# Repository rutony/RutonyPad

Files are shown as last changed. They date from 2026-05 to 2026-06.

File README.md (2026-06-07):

# RutonyPad

Небольшая беспроводная BLE-клавиатура на 8 кнопок для управления OBS и другими горячими клавишами. Проект вырос из идеи “сделать за пару часов подарок”, а в итоге прошел через китайский клон nRF52840, тестер пинов, несколько версий корпуса, пайку, веб-конфигуратор и отдельный режим настройки.

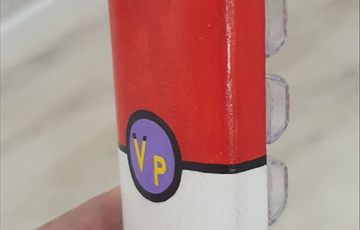
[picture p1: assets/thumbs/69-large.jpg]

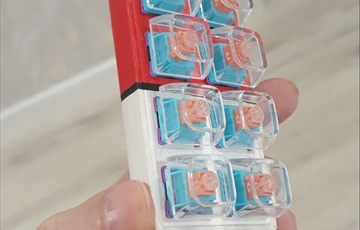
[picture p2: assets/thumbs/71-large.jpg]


## Что внутри

- прошивка устройства: [firmware/RutonyPad10/RutonyPad10.ino](firmware/RutonyPad10/RutonyPad10.ino);
- тестер пинов для китайского nRF52840 Pro Micro: [firmware/TesterPins/TesterPins.ino](firmware/TesterPins/TesterPins.ino);
- веб-страница для настройки клавиш: [web/index.html](web/index.html);
- STL-модель корпуса: [assets/models/RutonyPad-Box-v3.2.stl](assets/models/RutonyPad-Box-v3.2.stl);
- STL-крышки/клавиш: [assets/models/RutonyPad-Buttons-v1.1.stl](assets/models/RutonyPad-Buttons-v1.1.stl);
- фотографии процесса и схемы: [assets/images](assets/images).

Полезные внешние ссылки:

- схема устройства в Cirkit Designer: <https://app.cirkitdesigner.com/project/74aa2c99-3412-43d3-a665-44ffdaccba8f>;
- корпус в Tinkercad: <https://www.tinkercad.com/things/2l7U8HlfgIG-rutonypad-v31>.

## Как пользоваться

1. Залить прошивку [RutonyPad10.ino](firmware/RutonyPad10/RutonyPad10.ino) на nRF52840.
2. Подключить кнопки к пинам: `D33`, `D2`, `D20`, `D21`, `D23`, `D1`, `D12`, `D11`.
3. Подключить делитель батареи к `D18`.
4. В обычном режиме использовать устройство как Bluetooth-клавиатуру и определяется как RutonyPad.
5. Для настройки, удалить устройство если оно спарено, зажать крайние кнопки по диагонали примерно на 10 секунд. Устройство должно уже определиться как RutonyCfg. Значит оно перешло в режим конфигурации. Не добавлять его как обычное блютус устройство.
6. Открыть [web/index.html](web/index.html) в браузере с поддержкой Web Bluetooth. И подключить RutonyCfg.
7. Настроить клавиши и вернуться в режим клавиатуры.
8. Если не была нажата кнопка режима клавиатуры, зажать диагональные кнопки для смены режима - в режим клавиатуры.

## Что получилось

Получилось маленькое беспроводное устройство на 8 клавиш, которое:

- работает как BLE HID-клавиатура;
- умеет показывать заряд батареи;
- живет от аккумулятора примерно 2,5-3 недели;
- переключается в отдельный режим конфигурации комбинацией крайних кнопок по диагонали;
- настраивается через веб-страницу без перепрошивки;
- собрано в напечатанном корпусе.

## Идея

Все началось на стриме у Хели: <https://twitch.tv/vpaname>. Она любит танцевать, но управлять компьютером, когда стоишь, не очень удобно. Нужна была мини-клавиатура для OBS и горячих клавиш.

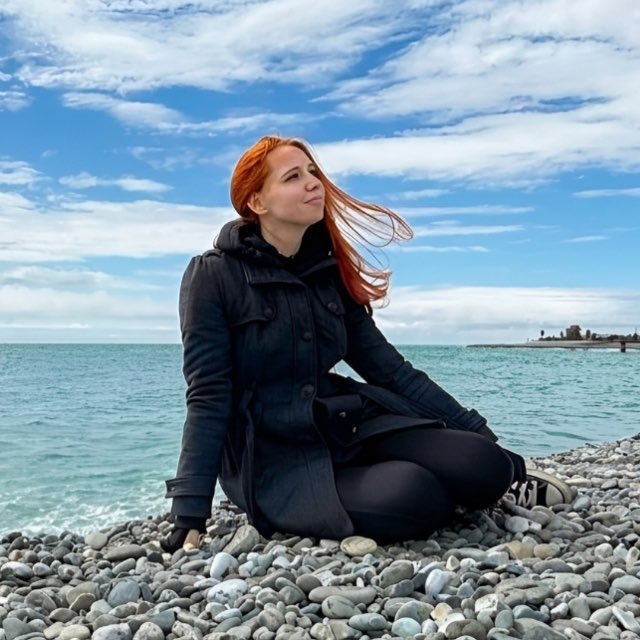
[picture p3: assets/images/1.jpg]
Хели


Быстрый поиск показал, что готовые устройства существуют, но стоят ощутимо дороже, чем хотелось. Я прикинул бюджет в районе 2-3 тысяч рублей и решил сделать свою версию. До дня рождения оставалось около трех месяцев, так что идея выглядела как хороший подарок и проект “буквально на пару часов”. По итогу, конечно, эти “пара часов” превратились в 3 месяца безудержного веселья. Но было интересно попробовать себя в роли инженера, коим я и являюсь. Опыт есть в создании устройств, но они в основном были в разы проще и не такие комплексные. 

## Контроллер и первые грабли

После общения с нейронкой стало казаться, что задача простая: нужна небольшая плата, Bluetooth, несколько кнопок и аккумулятор. Wi-Fi не нужен, основа устройства - контроллер.

Я заказал на Ozon модуль NRF52840, совместимый с Nice!Nano V2.0 / Bluetooth Pro Micro NRF52840. С AliExpress ждать пришлось бы дольше, да и было непонятно, что именно приедет.

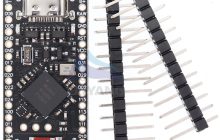
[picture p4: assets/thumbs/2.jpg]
Контроллер


Пока плата ехала, я прикинул корпус:

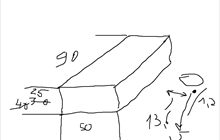
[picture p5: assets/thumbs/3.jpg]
Первый набросок корпуса


Когда контроллер приехал, начались первые тесты в Arduino IDE. Задачи были две: написать прошивку и потом все это спаять. На макетной плате все вело себя отвратительно: то работает, то отваливается, то кажется, что ошибка в коде, то кажется, что в проводах.

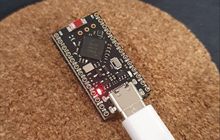
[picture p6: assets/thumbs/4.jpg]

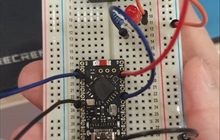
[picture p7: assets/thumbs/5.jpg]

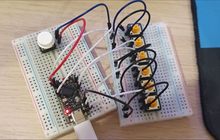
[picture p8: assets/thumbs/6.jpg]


В итоге выяснилось, что часть проблем была в макетной плате. Эти платы удобны для быстрых проверок, но если контакт плохой, начинается настоящая лотерея. А еще обнаружилась проблема с самим китайским клоном контроллера.

В комплекте была схема пинов, но нигде не было сказано, что часть пинов не работает или имеет другую нумерацию. Несколько дней ушло на ковыряние неочевидных проблем.

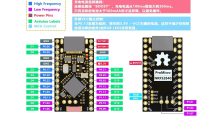
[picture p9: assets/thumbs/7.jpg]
Схема пинов


Чтобы разобраться, я написал отдельный скетч-тестер. Он сканирует пины: я замыкаю их на GND и смотрю, какой пин реально отзывается. Так стало понятно, что на китайском клоне половина заявленных пинов действительно может оказаться бесполезной.

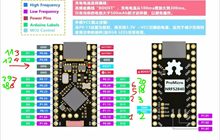
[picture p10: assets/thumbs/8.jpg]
Тест пинов


Скетч тестера лежит здесь: [firmware/TesterPins/TesterPins.ino](firmware/TesterPins/TesterPins.ino).

## Прошивка

Прошивку сначала помогала собирать нейронка, но она честно наворотила ровно то, что я попросил: 8 кнопок, Bluetooth и отдельную кнопку включения. Проблема была в том, что часть выбранных пинов не работала, а отдельная кнопка питания в итоге оказалась не такой уж нужной.

Пока я правил прошивку, появилась идея использовать служебную комбинацию кнопок для перехода в режим настройки. Логика получилась такая:

- в обычном режиме устройство работает как BLE HID-клавиатура;
- если зажать две крайние кнопки примерно на 5 секунд, устройство перезагружается в режим конфигурации;
- в режиме конфигурации оно не создает HID-клавиатуру, зато его можно настроить через веб-страницу;
- повторная служебная комбинация или кнопка на странице возвращает устройство в обычный режим.

Еще одна важная доработка - отображение заряда аккумулятора в Bluetooth-устройствах. Для этого пришлось отказаться от отдельной кнопки питания, поставить резисторы и снимать показания с контроллера заряда. Зато теперь в системе видно процент батареи.

По умолчанию устройство большую часть времени спит. Сон почти не ест аккумулятор. По расчетам и в реальности автономность получилась примерно 2,5-3 недели.

Основная прошивка лежит здесь: [firmware/RutonyPad10/RutonyPad10.ino](firmware/RutonyPad10/RutonyPad10.ino).

## Компоненты

Основные детали, которые использовались:

- модуль NRF52840, совместимый с Nice!Nano V2.0 / Bluetooth Pro Micro NRF52840;
- аккумулятор 602035, 500 mAh, 3,7 V;
- контроллер заряда TP4056 USB Type-C с защитой;
- кабели JST PH 2.0 мм;
- свитчи Redragon Bullet-R;
- сокеты Kailh MX Socket, чтобы не паять свитчи намертво;
- паяльник ALIENTEK T90B;
- припой ПОС-61 с канифолью.

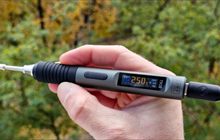
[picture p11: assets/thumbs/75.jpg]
ALIENTEK T90B


Так как я паял не так что бы много и паять пришлось бы достаточно много мелких деталей, я бы одурел делать это советским паяльником. Поэтому был при обретен новый современный. Паяльник, кстати, оказался очень крутым, покупался по наводке Гайвера (Заметки Ардуинщика, иногда посматривал его видосы, а тут еще и пригодилось): быстрый разогрев за 5-10 секунд, питание от обычного повербанка, настройка температуры и удобная ручка. Важный момент: нужен мягкий USB-C кабель под высокий вольтаж. В комплекте он был.

## Схема

Финальная схема подключения компонентов:

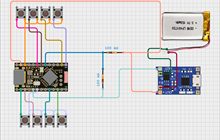
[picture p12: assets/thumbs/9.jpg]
Схема распайки


Проект схемы: <https://app.cirkitdesigner.com/project/74aa2c99-3412-43d3-a665-44ffdaccba8f>

Изначально в схеме была отдельная кнопка включения и программирования, но позже я от нее отказался.

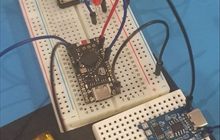
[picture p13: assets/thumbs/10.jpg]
Планирование схемы


## Пайка и первые тесты

Когда прошивка, схема и веб-страница для программирования клавиш были готовы, началась пайка.

Сначала припаивается силовой провод. Тут важно сделать все аккуратно: ничего не должно торчать, все закрывается оплеткой.

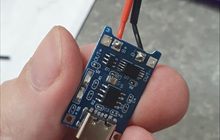
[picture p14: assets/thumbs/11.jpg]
Пайка питания


Потом первые тесты: устройство уже видно в компьютере без прямого подключения. На заднем плане еще старая схема с отдельной кнопкой включения. Но уже видно что устройство определилось как блютус клавиатура.

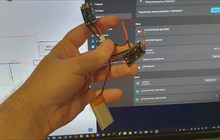
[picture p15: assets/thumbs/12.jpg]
Первый беспроводной тест


Дальше - пайка всего устройства. Почти сразу стало понятно, что без “третьей руки” будет тяжело: контакты мелкие, плату нужно держать, а видеть хочется больше. Ее я заказывал с перерывом в неделю, я в этот момент был в Москве на Гамеднях и с подругой Олей (<https://www.twitch.tv/trolechka_>) стояли в ночной шавухе. Я ей рассказывал чуть деталей, мол вот собираю уже почти все готово, но паять трудно, была бы третья рука, было бы проще. А сам думаю какого черта.. И там же заказал, пока готовилась шавуха. Хеля, кстати, отказалась от шавухи и не пошла с нами, она на диете.

Лупа с третьей рукой нереально сильно упростила жизнь и ускорила пайку.

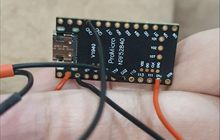
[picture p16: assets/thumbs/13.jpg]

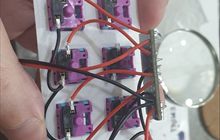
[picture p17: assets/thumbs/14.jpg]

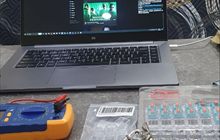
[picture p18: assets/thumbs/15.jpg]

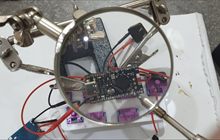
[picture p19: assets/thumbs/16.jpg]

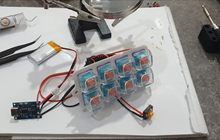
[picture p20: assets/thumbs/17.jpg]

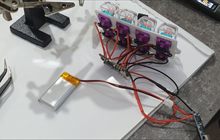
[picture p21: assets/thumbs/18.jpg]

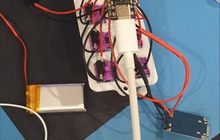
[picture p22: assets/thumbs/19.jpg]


## Веб-конфигуратор

Для настройки клавиш сделана отдельная страница: [web/index.html](web/index.html).

Она подключается к устройству в режиме конфигурации через Web Bluetooth и позволяет назначать поведение кнопок. После настройки можно вернуть устройство в режим клавиатуры прямо со страницы.

Пришлось повозиться со страницей, в целом нейронка все быстро сверстала, даже какой то общий стиль. Но она упорно путала идентификаторы устройства. Поэтому нужна была постоянная правка, то в скетче, то на самой странице. Но я справился.

Саму же страницу я разместил у себя на сайте. Вспомнив такой фильм как Сеть (1995), я добавил маленький символ Пи, по нажатию на который открывается конфигуратор. В фильме Сандра Буллок, через него получала доступ к базе данных через бекдок. Тут конечно не взлом как в фильме, но все же :D

## Корпус

Отдельная глава боли - корпус и покраска.

Сначала я сделал корпус высотой 40 мм, но после печати стало понятно, что он смотрится плохо: слишком высокий, плюс при печати лежа появились “лесенки”. Тогда я решил печатать стоя (не я сам стоял, а модель, я в этот момент занимался своими делами) и уменьшил высоту до 25 мм.

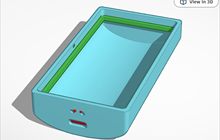
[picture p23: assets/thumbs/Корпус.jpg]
Проект корпуса


Модель в Tinkercad: <https://www.tinkercad.com/things/2l7U8HlfgIG-rutonypad-v31>

У модели версия 3.1, потому что было сделано 3 разные версии, под 40мм, под 25мм, и потом я понял что защелки которые я хотел сделать это ерунда, достаточно просто сделать "балкончик". То нужна полка для контроллера заряда, то больше места под крышку, то защелки получаются слишком хлипкими. Всего модель печаталась 11 раз, до конца печати дожили 4 версии. В одном из заходов даже сломался принтер: датчик температуры сопла показывал постоянные 220 градусов...

Сначала я решил перепрошить принтер, вдруг это программная какая то ошибка. Результата никакого не было. Пришлось разобрать сопло принтера, проверить ничего ли не сломалось, проверить нужно ли менять датчик. Было предположение что из-за постоянных срывов печати сопло ударило по модели, от чего она слетела и повредился датчик. Но он пришел в себя и заработал после разбоки. Поэтому принтер благополучно был собран обратно и отправлен печатать новую деталь.

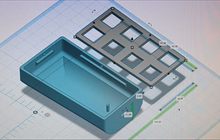
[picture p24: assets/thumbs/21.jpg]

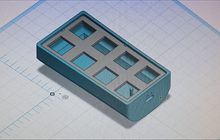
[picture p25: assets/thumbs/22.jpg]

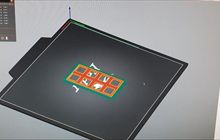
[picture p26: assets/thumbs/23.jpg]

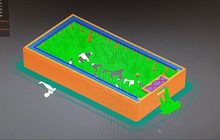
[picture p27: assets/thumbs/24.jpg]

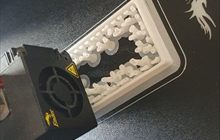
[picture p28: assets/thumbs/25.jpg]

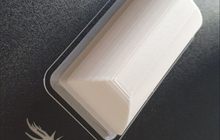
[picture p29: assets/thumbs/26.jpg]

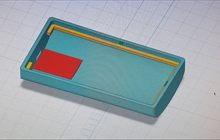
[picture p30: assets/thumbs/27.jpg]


В итоге корпус все-таки напечатался. Как выяснилось позже, это был только второй корпус.

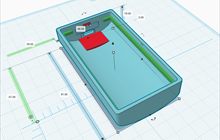
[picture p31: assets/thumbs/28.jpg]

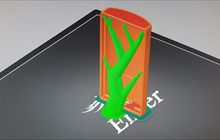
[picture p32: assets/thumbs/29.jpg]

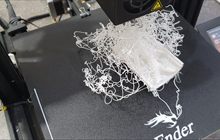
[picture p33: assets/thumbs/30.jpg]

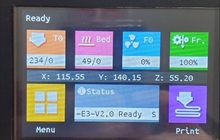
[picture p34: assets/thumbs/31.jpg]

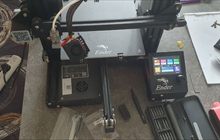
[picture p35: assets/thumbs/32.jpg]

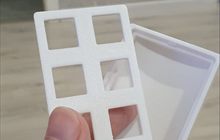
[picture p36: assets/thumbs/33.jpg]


Дальше пошла отделка: шкурка, грунтовка, снова шкурка, покраска акрилом. Опыта было ноль, поэтому сначала вышло плохо. Потом после советов и мучений выяснилось, что губка дает более приятный результат. 

Вспоминая где то на задворках памяти, что да... где то я такое видел, я взался за губку. И как результат появилась шагрень - мелкие неровности поверхности. Для устройства, которое хочется держать в руке, это неприятно. Я надеялся, что лак выровнит покрытие. Но... Не выровнял. Там, где поверхность была гладкой, все стало красиво, а там, где была шагрень, стало еще хуже.

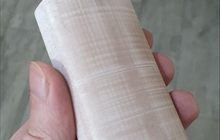
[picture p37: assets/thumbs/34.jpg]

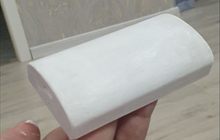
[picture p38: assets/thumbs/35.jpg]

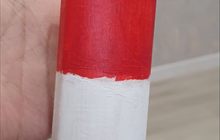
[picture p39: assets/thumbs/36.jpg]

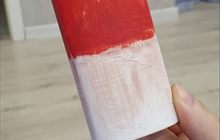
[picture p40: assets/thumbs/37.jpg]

<a href="assets/images/38.jpg">Лак и шагрень</a>
<a href="assets/images/39.jpg">Лак и шагрень</a>
<a href="assets/images/40.jpg">Лак и шагрень</a>
<a href="assets/images/41.jpg">Лак и шагрень</a>
<a href="assets/images/42.jpg">Лак и шагрень</a>

Пришлось печатать еще раз. Потом снова шкурить, шпаклевать, красить, ждать между слоями, покрывать лаком и сушить. В этот раз я уже выдерживал паузы дольше: между слоями краски около 2 часов, между слоями лака около 4 часов, потом сутки на сушку.

<a href="assets/images/43.jpg">Вторая попытка</a>
<a href="assets/images/44.jpg">Вторая попытка</a>
<a href="assets/images/45.jpg">Вторая попытка</a>

И тут новая проблема: модель все еще слегка липкая. Быстрый поиск подсказал, что видимо слой лака был слишком толстым и нужна сушка в каком то теплом, сухом месте где то 2-3 суток. Не долго думая я понес в гардероб, где она и пролежала 2 дня. И как результат сушки в гардеробе белая часть облепилась ворсинками. Гардероб оказался худшим местом для сушки свежего лака. Как оказалось, если я правильно понял, от одежды, даже если там не ходить очень много мелких частиц. Лучше бы конечно поместил в какую то закрытую коробку и поставил в ванной у палатенце сушителя.

<a href="assets/images/46.jpg">Ворсинки на покрытии</a>

На этом моменте я сдался и позвал тяжелую артиллерию - Леру: <https://twitch.tv/solodvalery>. Для нее была напечатана еще одна модель в быстром темпе, а вместе с ней отправились лаки, краски, грунтовки, шкурки и все остальное для нормальной покраски.

Было решено капитально переделать способ печати: выставить максимальные режимы сглаживания, спаивания и поддержек, это увеличило время печати почти в 2 раза, с 3.5 часов до 7. А первая модель раслоилась при конце печати... Так что печаталась аж 2 раза (это уже была наверное 10 печать корпуса). Я просто устал от бесконечного брака. Поэтому напечатал модель под углом, чтобы она была максимально крепкой.

<a href="assets/images/47.jpg">Финальные попытки с корпусом</a>
<a href="assets/images/48.jpg">Финальные попытки с корпусом</a>
<a href="assets/images/57.jpg">Печать под углом</a>
<a href="assets/images/58.jpg">Печать под углом</a>
<a href="assets/images/59.jpg">Печать под углом</a>

Лере были отправлены все мои поделки, в том числе пара из многочисленных неудачных печатей. Она сказала надо бы глянуть, как не делать :D

<a href="assets/images/49.jpg">Поделки для Леры</a>

Она зашкурила и покрыла корпус грунтом, а потом наметила логотип. Правда, логотип оказался неправильным, а пока мы переписывались, из-за моего сбитого режима он уже был покрашен неверно. Поэтому Лера решила поправить его прямо на уже покрашенной модели. Но в любом случае получилось аккуратно.

<a href="assets/images/50.jpg">Грунт и логотип</a>
<a href="assets/images/51.jpg">Грунт и логотип</a>
<a href="assets/images/52.jpg">Грунт и логотип</a>
<a href="assets/images/53.jpg">Грунт и логотип</a>
<a href="assets/images/54.jpg">Грунт и логотип</a>

Итак, корпус готов. Выглядит отлично. Гораздо лучше, чем мои поделки. Сразу видно, что у Леры есть опыт.

Меня больше удивило, что создание и раскраска корпуса заняла чуть ли не в 2 раза больше времени чем разработка и пайка устройства. Это был долгий процесс с кучей проблем. Без опыта тут никуда.

<a href="assets/images/55.jpg">Готовый корпус</a>
<a href="assets/images/56.jpg">Готовый корпус</a>

## Финальная сборка

Что ж, пришло время собирать устройство. Ставим свитчи. Ставим контроллер заряда и запаиваем его пластиком, чтобы он не болтался, а еще был упор: время от времени на него будет давить USB-C при зарядке. Добавляем термостойкую изоленту. Не уверен, что она тут обязательна, но пусть будет.

<a href="assets/images/60.jpg">Финальная сборка</a>
<a href="assets/images/61.jpg">Финальная сборка</a>
<a href="assets/images/62.jpg">Финальная сборка</a>
<a href="assets/images/63.jpg">Финальная сборка</a>

Добавляем аккумулятор и приклеиваем его термостойким скотчем. Он все же тяжеловат и может болтаться, поэтому фиксируем аж несколько раз. Пластиком не запаивал: нужен вариант замены. И добавляем петельку на руку.

<a href="assets/images/64.jpg">Аккумулятор и петля</a>
<a href="assets/images/65.jpg">Аккумулятор и петля</a>

Теперь выравниваем провода и состыковываем крышку с корпусом. Верхняя крышка специально делалась без зазора в миллиметр, чтобы ее можно было просто поставить и не клеить. А если что-то понадобится поправить, корпус можно вскрыть: снять свитч и аккуратно вытянуть крышку со свитчами. Ставим прозрачные кейкапы.

<a href="assets/images/66.jpg">Сборка корпуса</a>
<a href="assets/images/67.jpg">Сборка корпуса</a>

Итоговый результат.

<a href="assets/images/68.jpg">Итоговый результат</a>
<a href="assets/images/69.jpg">Итоговый результат</a>
<a href="assets/images/71.jpg">Итоговый результат</a>
<a href="assets/images/72.jpg">Итоговый результат</a>
<a href="assets/images/73.jpg">Итоговый результат</a>
<a href="assets/images/74.jpg">Итоговый результат</a>

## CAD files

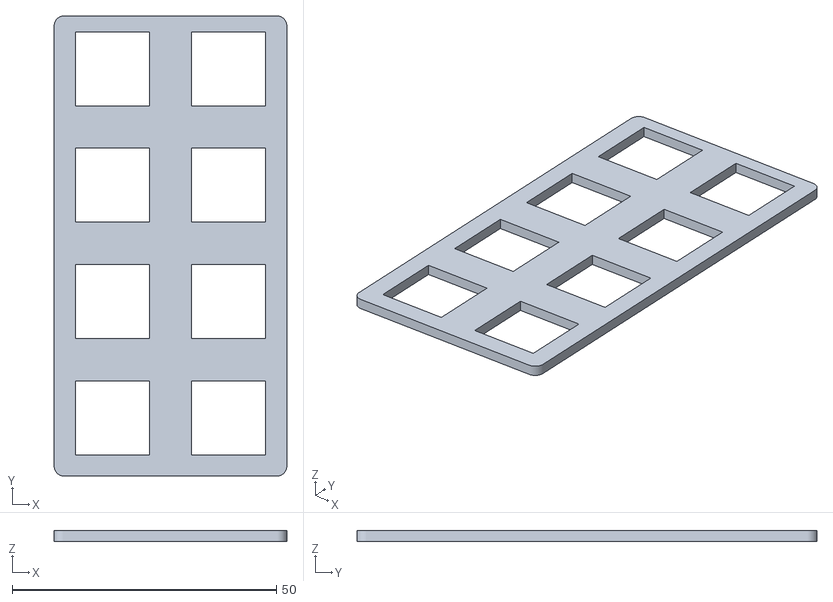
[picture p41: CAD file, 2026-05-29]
assets/models/RutonyPad-Buttons-v1.1.stl
44.0 x 87.0 x 2.00

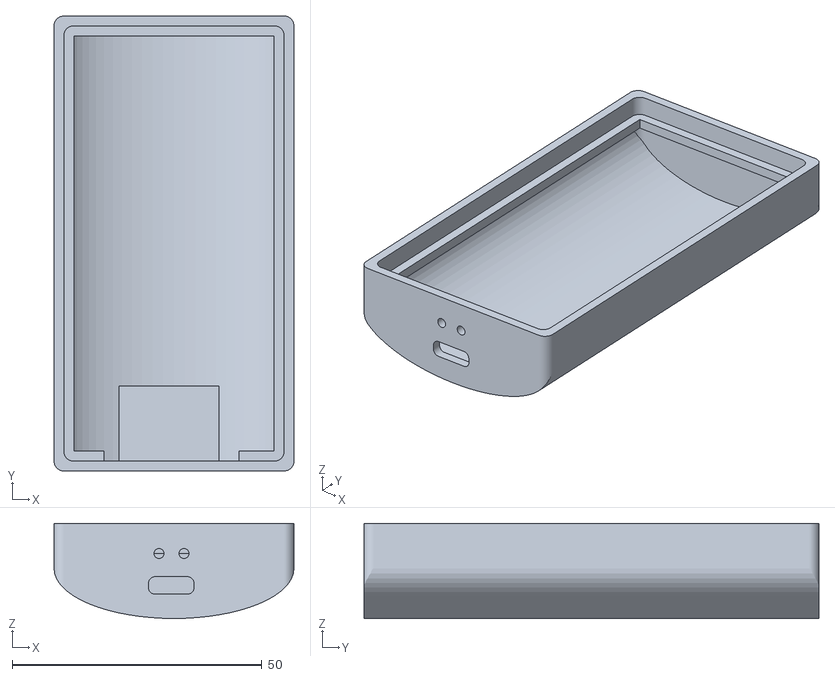
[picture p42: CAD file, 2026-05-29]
assets/models/RutonyPad-Box-v3.2.stl
48.0 x 91.0 x 19.0

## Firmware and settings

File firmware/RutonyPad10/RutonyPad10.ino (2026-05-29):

/*
 * RutonyPad — combo config firmware, reboot-separated modes
 *
 * Почему так:
 *   На Windows нельзя надежно превратить уже запущенную BLE HID-клавиатуру
 *   в чистое config-устройство без перезапуска BLE/GATT. Поэтому вход в настройку
 *   теперь сохраняет флаг режима и делает программный reset. Питание/аккумулятор
 *   отключать не нужно.
 *
 * Порядок клавиш:
 *   1 D33, 2 D2, 3 D20, 4 D21, 5 D23, 6 D1, 7 D12, 8 D11
 *
 * Служебная комбинация:
 *   NORMAL: D33 + D11 удерживать 5 сек -> перезагрузка в CONFIG ONLY, HID не создается
 *   CONFIG: D33 + D11 удерживать 2 сек -> перезагрузка в NORMAL, HID создается
 *   На веб-странице кнопка "Вернуться в режим клавиатуры" делает то же самое.
 */

#include <bluefruit.h>
#include <Adafruit_LittleFS.h>
#include <InternalFileSystem.h>
using namespace Adafruit_LittleFS_Namespace;

// ─── ПИНЫ ───────────────────────────────────────────────────────────────────
const int SWITCH_PINS[8] = {33, 2, 20, 21, 23, 1, 12, 11};
const int BATT_PIN = 18;  // D18 — делитель батареи

const int COMBO_LEFT_INDEX  = 0; // D33
const int COMBO_RIGHT_INDEX = 7; // D11
const unsigned long ENTER_CONFIG_MS = 5000UL;
const unsigned long EXIT_CONFIG_MS  = 2000UL;

// ─── ФАЙЛЫ ──────────────────────────────────────────────────────────────────
File fsFile(InternalFS);
#define CONFIG_FILE "/rutonypad.cfg"
#define BOOTMODE_FILE "/rutonypad.mode"
#define MODE_NORMAL 0x00
#define MODE_CONFIG 0xC3

// ─── КОНФИГ КЛАВИШ ──────────────────────────────────────────────────────────
struct KeyConfig {
  uint8_t modifier;
  uint8_t keycode;
};

const KeyConfig DEFAULT_CONFIGS[8] = {
  {0x07, 0x1E}, {0x07, 0x1F}, {0x07, 0x20}, {0x07, 0x21},
  {0x07, 0x22}, {0x07, 0x23}, {0x07, 0x24}, {0x07, 0x25},
};

KeyConfig configs[8];

// ─── BLE ────────────────────────────────────────────────────────────────────
BLEDis         bledis;
BLEHidAdafruit blehid;
BLEBas         blebas;

// UUID RutonyPad config service.
// В Bluefruit 128-bit UUID задаётся байтами в little-endian порядке.
const uint8_t UUID_SERVICE[] = {0xA1,0xC9,0x43,0x4F,0x7A,0x2A,0xB0,0xBB,0xE9,0x4C,0x56,0x0E,0x20,0x9A,0x1D,0x6F}; // 6f1d9a20-0e56-4ce9-bbb0-2a7a4f43c9a1
const uint8_t UUID_READ[]    = {0x73,0x8E,0xF0,0x8C,0x79,0x6D,0xE1,0xA5,0x9B,0x4F,0xD6,0x13,0xD8,0xD4,0xF3,0xB3}; // b3f3d4d8-13d6-4f9b-a5e1-6d798cf08e73
const uint8_t UUID_WRITE[]   = {0xBF,0xA3,0xC8,0x03,0xF7,0xE0,0x6C,0x9E,0x5C,0x4D,0xD0,0x71,0xD5,0xF6,0xDC,0x4A}; // 4adcf6d5-71d0-4d5c-9e6c-e0f703c8a3bf
const uint8_t UUID_CONTROL[] = {0x0E,0x3C,0x79,0xF2,0x49,0x4B,0x13,0xB6,0xE6,0x4C,0xA2,0x8E,0x7B,0x22,0xF1,0x5A}; // 7b22f15a-a28e-4ce6-b613-4b49f2793c0e

BLEService        cfgService(UUID_SERVICE);
BLECharacteristic cfgRead(UUID_READ);
BLECharacteristic cfgWrite(UUID_WRITE);
BLECharacteristic cfgControl(UUID_CONTROL);

// ─── СОСТОЯНИЕ ──────────────────────────────────────────────────────────────
bool configMode = false;
bool hidStarted = false;
uint16_t currentConn = BLE_CONN_HANDLE_INVALID;

bool lastState[8];
bool keyPressed[8];
unsigned long lastDebounce[8];
const unsigned long DEBOUNCE_MS = 50;

bool comboWasDown = false;
bool comboConsumed = false;
unsigned long comboStart = 0;

// ─── БАТАРЕЯ ────────────────────────────────────────────────────────────────
const float BATT_FULL_MV  = 4200.0f;
const float BATT_EMPTY_MV = 3000.0f;
const float DIVIDER_RATIO = 2.0f;
const float ADC_REF_MV    = 3000.0f;  // AR_INTERNAL_3_0
const int   ADC_BITS      = 12;

unsigned long lastBattCheck = 0;
const unsigned long BATT_INTERVAL_MS = 60000UL;
uint8_t lastBattPercent = 255;

void startNormalAdv();
void startConfigAdv();
void updateCfgReadChar();
void rebootToMode(uint8_t modeByte);

// ─── BOOT MODE ──────────────────────────────────────────────────────────────
uint8_t readBootMode() {
  uint8_t mode = MODE_NORMAL;
  if (fsFile.open(BOOTMODE_FILE, FILE_O_READ)) {
    if (fsFile.read(&mode, 1) != 1) mode = MODE_NORMAL;
    fsFile.close();
  }
  return mode;
}

void saveBootMode(uint8_t modeByte) {
  InternalFS.remove(BOOTMODE_FILE);
  if (fsFile.open(BOOTMODE_FILE, FILE_O_WRITE)) {
    fsFile.write(&modeByte, 1);
    fsFile.close();
  }
}

void rebootToMode(uint8_t modeByte) {
  saveBootMode(modeByte);
  if (Bluefruit.connected() && currentConn != BLE_CONN_HANDLE_INVALID) {
    if (hidStarted) blehid.keyRelease();
    delay(30);
    Bluefruit.disconnect(currentConn);
    delay(250);
  }
  Serial.println(modeByte == MODE_CONFIG ? "Rebooting to CONFIG ONLY..." : "Rebooting to NORMAL keyboard...");
  Serial.flush();
  delay(100);
  NVIC_SystemReset();
}

// ─── BATTERY ────────────────────────────────────────────────────────────────
uint8_t readBatteryPercent() {
  int raw = analogRead(BATT_PIN);
  float pinMV = (float)raw / ((1 << ADC_BITS) - 1) * ADC_REF_MV;
  float battMV = pinMV * DIVIDER_RATIO;

  Serial.print("BAT raw="); Serial.print(raw);
  Serial.print(" pin="); Serial.print(pinMV, 1); Serial.print(" mV");
  Serial.print(" batt="); Serial.print(battMV, 1); Serial.println(" mV");

  if (battMV >= BATT_FULL_MV) return 100;
  if (battMV <= BATT_EMPTY_MV) return 0;
  return (uint8_t)((battMV - BATT_EMPTY_MV) / (BATT_FULL_MV - BATT_EMPTY_MV) * 100.0f);
}

void updateBattery(bool force = false) {
  uint8_t pct = readBatteryPercent();
  if (force || pct != lastBattPercent) {
    lastBattPercent = pct;
    blebas.write(pct);
    Serial.print("Battery level updated: "); Serial.print(pct); Serial.println("%");
  }
}

// ─── CONFIG FILE ────────────────────────────────────────────────────────────
void resetDefaultsInRam() {
  memcpy(configs, DEFAULT_CONFIGS, sizeof(configs));
}

void saveConfig() {
  InternalFS.remove(CONFIG_FILE);
  if (fsFile.open(CONFIG_FILE, FILE_O_WRITE)) {
    fsFile.write((uint8_t*)configs, sizeof(configs));
    fsFile.close();
    Serial.println("Config saved to flash.");
  } else {
    Serial.println("ERROR: Cannot open config file for write!");
  }
}

void loadConfig() {
  resetDefaultsInRam();
  if (fsFile.open(CONFIG_FILE, FILE_O_READ)) {
    size_t n = fsFile.read((uint8_t*)configs, sizeof(configs));
    fsFile.close();
    if (n == sizeof(configs)) {
      Serial.println("Config loaded from flash.");
    } else {
      Serial.println("Config file size mismatch, using defaults.");
      resetDefaultsInRam();
    }
  } else {
    Serial.println("No config file, using defaults.");
  }
}

// ─── CONFIG SERVICE ─────────────────────────────────────────────────────────
void updateCfgReadChar() {
  uint8_t buf[16];
  for (int i = 0; i < 8; i++) {
    buf[i * 2]     = configs[i].modifier;
    buf[i * 2 + 1] = configs[i].keycode;
  }
  cfgRead.write(buf, 16);
}

void onCfgWrite(uint16_t conn_hdl, BLECharacteristic* chr, uint8_t* data, uint16_t len) {
  (void)conn_hdl;
  (void)chr;

  if (len != 16) {
    Serial.print("Wrong config length: "); Serial.println(len);
    return;
  }

  for (int i = 0; i < 8; i++) {
    configs[i].modifier = data[i * 2];
    configs[i].keycode  = data[i * 2 + 1];
  }

  saveConfig();
  updateCfgReadChar();
  Serial.println("Config received via BLE and saved.");
}

void onControlWrite(uint16_t conn_hdl, BLECharacteristic* chr, uint8_t* data, uint16_t len) {
  (void)conn_hdl;
  (void)chr;
  if (len < 1) return;

  if (data[0] == 0xA1) {
    Serial.println("CONTROL: return to keyboard mode");
    rebootToMode(MODE_NORMAL);
  } else if (data[0] == 0xA2) {
    Serial.println("CONTROL: reset defaults");
    resetDefaultsInRam();
    saveConfig();
    updateCfgReadChar();
  } else {
    Serial.print("CONTROL: unknown command 0x"); Serial.println(data[0], HEX);
  }
}

void setupConfigService() {
  cfgService.begin();

  cfgRead.setProperties(CHR_PROPS_READ);
  cfgRead.setPermission(SECMODE_OPEN, SECMODE_NO_ACCESS);
  cfgRead.setFixedLen(16);
  cfgRead.begin();
  updateCfgReadChar();

  cfgWrite.setProperties(CHR_PROPS_WRITE | CHR_PROPS_WRITE_WO_RESP);
  cfgWrite.setPermission(SECMODE_OPEN, SECMODE_OPEN);
  cfgWrite.setFixedLen(16);
  cfgWrite.setWriteCallback(onCfgWrite);
  cfgWrite.begin();

  cfgControl.setProperties(CHR_PROPS_WRITE | CHR_PROPS_WRITE_WO_RESP);
  cfgControl.setPermission(SECMODE_OPEN, SECMODE_OPEN);
  cfgControl.setFixedLen(1);
  cfgControl.setWriteCallback(onControlWrite);
  cfgControl.begin();
}

// ─── BLE CALLBACKS ──────────────────────────────────────────────────────────
void onConnect(uint16_t conn_hdl) {
  currentConn = conn_hdl;
  Serial.print("BLE connected, handle: "); Serial.println(conn_hdl);
  updateCfgReadChar();
  updateBattery(true);
}

void onDisconnect(uint16_t conn_hdl, uint8_t reason) {
  (void)conn_hdl;
  currentConn = BLE_CONN_HANDLE_INVALID;
  Serial.print("BLE disconnected, reason: 0x"); Serial.println(reason, HEX);

  if (configMode) startConfigAdv();
  else startNormalAdv();
}

// ─── ADVERTISING ────────────────────────────────────────────────────────────
void commonAdvSetup() {
  Bluefruit.Advertising.stop();
  Bluefruit.Advertising.clearData();
  Bluefruit.ScanResponse.clearData();
  Bluefruit.Advertising.addFlags(BLE_GAP_ADV_FLAGS_LE_ONLY_GENERAL_DISC_MODE);
  Bluefruit.Advertising.addTxPower();
  Bluefruit.ScanResponse.addName();
  Bluefruit.Advertising.setInterval(32, 244);
  Bluefruit.Advertising.setFastTimeout(30);
}

void startNormalAdv() {
  commonAdvSetup();
  Bluefruit.Advertising.addAppearance(BLE_APPEARANCE_HID_KEYBOARD);
  Bluefruit.Advertising.addService(blehid);
  Bluefruit.ScanResponse.addService(cfgService);
  Bluefruit.ScanResponse.addService(blebas);
  Bluefruit.Advertising.restartOnDisconnect(true);
  Bluefruit.Advertising.start(0);
  Serial.println("Advertising started: NORMAL as RutonyPad: HID + Config + Battery.");
}

void startConfigAdv() {
  commonAdvSetup();
  Bluefruit.Advertising.addService(cfgService);
  Bluefruit.ScanResponse.addService(blebas);
  Bluefruit.Advertising.restartOnDisconnect(true);
  Bluefruit.Advertising.start(0);
  Serial.println("Advertising started: CONFIG ONLY as RutonyCfg. HID service was NOT created on this boot.");
}

// ─── HID HELPERS ────────────────────────────────────────────────────────────
void sendKeyDown(int i) {
  if (!hidStarted || !Bluefruit.connected() || configMode) return;
  uint8_t keycodes[6] = {configs[i].keycode, 0, 0, 0, 0, 0};
  blehid.keyboardReport(configs[i].modifier, keycodes);
}

void sendKeyTap(int i) {
  if (!hidStarted || !Bluefruit.connected() || configMode) return;
  uint8_t keycodes[6] = {configs[i].keycode, 0, 0, 0, 0, 0};
  blehid.keyboardReport(configs[i].modifier, keycodes);
  delay(20);
  blehid.keyRelease();
}

void releaseHidIfNeeded() {
  if (hidStarted && Bluefruit.connected() && !configMode) blehid.keyRelease();
}

// ─── SETUP ──────────────────────────────────────────────────────────────────
void setup() {
  Serial.begin(115200);
  delay(300);

  Serial.println();
  Serial.println("=== RutonyPad RutonyCfg FIXED UUID boot ===");
  Serial.println("D2 is an ordinary key. No physical power button.");

  InternalFS.begin();
  configMode = (readBootMode() == MODE_CONFIG);
  loadConfig();

  analogReadResolution(ADC_BITS);
  analogReference(AR_INTERNAL_3_0);
  pinMode(BATT_PIN, INPUT);

  for (int i = 0; i < 8; i++) {
    pinMode(SWITCH_PINS[i], INPUT_PULLUP);
    lastState[i] = HIGH;
    keyPressed[i] = false;
    lastDebounce[i] = 0;
  }

  Bluefruit.begin(1, 0);
  Bluefruit.setTxPower(4);
  Bluefruit.setName(configMode ? "RutonyCfg" : "RutonyPad");
  Serial.print("BLE name: "); Serial.println(configMode ? "RutonyCfg" : "RutonyPad");
  Bluefruit.Periph.setConnectCallback(onConnect);
  Bluefruit.Periph.setDisconnectCallback(onDisconnect);

  bledis.setManufacturer("Rutony");
  bledis.setModel(configMode ? "RutonyPad config only" : "RutonyPad keyboard");
  bledis.begin();

  blebas.begin();
  blebas.write(100);

  if (!configMode) {
    blehid.begin();
    hidStarted = true;
    setupConfigService();
    startNormalAdv();
    Serial.println("Boot mode: NORMAL, HID enabled.");
    Serial.println("Hold D33 + D11 for 5 sec to enter Web Config mode.");
  } else {
    hidStarted = false;
    setupConfigService();
    startConfigAdv();
    Serial.println("Boot mode: CONFIG ONLY, HID disabled.");
    Serial.println("Hold D33 + D11 for 2 sec or use web button to return to keyboard mode.");
  }

  lastBattCheck = millis() - BATT_INTERVAL_MS;
  Serial.println("Key order: D33, D2, D20, D21, D23, D1, D12, D11");
  Serial.println("=== RutonyPad ready ===");
}

// ─── LOOP ───────────────────────────────────────────────────────────────────
void loop() {
  unsigned long now = millis();

  if (now - lastBattCheck >= BATT_INTERVAL_MS) {
    lastBattCheck = now;
    updateBattery();
  }

  bool cur[8];
  for (int i = 0; i < 8; i++) cur[i] = digitalRead(SWITCH_PINS[i]);

  bool comboDown = (cur[COMBO_LEFT_INDEX] == LOW && cur[COMBO_RIGHT_INDEX] == LOW);

  if (comboDown && !comboWasDown) {
    comboStart = now;
    comboConsumed = false;
    comboWasDown = true;
    Serial.println("SERVICE COMBO started: D33 + D11");
  }

  if (comboDown && !comboConsumed) {
    unsigned long held = now - comboStart;
    if (!configMode && held >= ENTER_CONFIG_MS) {
      Serial.println("MODE request: CONFIG. Saving mode and rebooting with HID disabled...");
      comboConsumed = true;
      rebootToMode(MODE_CONFIG);
    } else if (configMode && held >= EXIT_CONFIG_MS) {
      Serial.println("MODE request: NORMAL. Saving mode and rebooting with HID enabled...");
      comboConsumed = true;
      rebootToMode(MODE_NORMAL);
    }
  }

  if (!comboDown && comboWasDown) {
    comboWasDown = false;
    comboStart = 0;
    if (cur[COMBO_LEFT_INDEX] == HIGH && cur[COMBO_RIGHT_INDEX] == HIGH) comboConsumed = false;
  }

  for (int i = 0; i < 8; i++) {
    bool isComboKey = (i == COMBO_LEFT_INDEX || i == COMBO_RIGHT_INDEX);

    if (lastState[i] == HIGH && cur[i] == LOW) {
      if (now - lastDebounce[i] > DEBOUNCE_MS) {
        lastDebounce[i] = now;
        keyPressed[i] = true;

        Serial.print("KEY DOWN: slot "); Serial.print(i + 1);
        Serial.print(" D"); Serial.println(SWITCH_PINS[i]);

        // D33/D11 отправляются tap'ом на отпускании, чтобы можно было отличить служебную комбинацию.
        if (!isComboKey && !configMode) sendKeyDown(i);
      }
    }

    if (lastState[i] == LOW && cur[i] == HIGH) {
      if (keyPressed[i]) {
        keyPressed[i] = false;

        Serial.print("KEY UP: slot "); Serial.println(i + 1);

        if (!configMode) {
          if (isComboKey) {
            if (!comboConsumed) sendKeyTap(i);
          } else {
            releaseHidIfNeeded();
          }
        }
      }
    }

    lastState[i] = cur[i];
  }

  delay(2);
}

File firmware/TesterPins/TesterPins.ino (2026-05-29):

/*
 * PinTester — находим рабочие пины на китайском NRF52840 Pro Micro
 *
 * Как пользоваться:
 *   1. Залей этот скетч
 *   2. Открой Serial Monitor (115200 бод)
 *   3. Замыкай пины на GND по одному
 *   4. Смотри что пишет в консоль
 *   5. Запиши какие пины реально откликаются
 *
 * Тестируем ВСЕ пины которые физически есть на плате.
 * Нам нужно найти 9 рабочих (8 свитчей + 1 кнопка питания).
 */

// Все пины которые обычно выведены на китайском Pro Micro NRF52840.
// Числа — это номера Arduino (не GPIO!), как они обычно маркируются в BSP.
// Если плата определилась как "Adafruit Feather nRF52840" — пины будут одни,
// если как "Generic nRF52840" — могут быть другие. Проверяем всё подряд.

const int TEST_PINS[] = {
  2, 3, 4, 5, 6, 7, 8, 9, 10,   // правый ряд (D2..D10)
  16, 14, 15, 18, 19, 20, 21,    // A0..A5 / дополнительные
  0, 1,                           // TX/RX — обычно Serial, но вдруг нужны
  11, 12, 13,                     // SPI / дополнительные
  22, 23, 24, 25,                 // если есть
  // GPIO напрямую — попробуем и так:
  // NRF52840 имеет P0.xx и P1.xx
  // В некоторых BSP они идут как 32+ для P1
  32, 33, 34, 35, 36, 37, 38, 39, 40, 41, 42, 43, 44, 45, 46, 47
};

const int PIN_COUNT = sizeof(TEST_PINS) / sizeof(TEST_PINS[0]);

bool lastState[60];   // с запасом
bool initialized[60]; // какие пины успешно инициализировались
unsigned long lastTrigger[60];
const unsigned long DEBOUNCE_MS = 100;

int totalWorking = 0;
int workingPins[60];

void setup() {
  Serial.begin(115200);
  delay(2000); // ждём открытия Serial Monitor

  Serial.println();
  Serial.println("╔══════════════════════════════════════╗");
  Serial.println("║       RutonyPad — Pin Tester         ║");
  Serial.println("╠══════════════════════════════════════╣");
  Serial.println("║  Замыкай пины на GND по одному.      ║");
  Serial.println("║  Рабочие пины покажутся здесь.       ║");
  Serial.println("╚══════════════════════════════════════╝");
  Serial.println();

  // Пробуем инициализировать каждый пин
  Serial.print("Инициализация пинов: ");
  for (int i = 0; i < PIN_COUNT; i++) {
    int pin = TEST_PINS[i];
    initialized[i] = false;
    lastTrigger[i] = 0;

    // Пробуем настроить пин — на некоторых китайских платах
    // обращение к несуществующему пину вызывает сбой.
    // pinMode на NRF52 не падает, просто игнорирует — но на всякий случай.
    pinMode(pin, INPUT_PULLUP);
    delay(2); // небольшая пауза чтобы подтяжка установилась

    // Читаем — если HIGH, значит пин живой (подтяжка работает)
    // Если читает LOW сразу — пин либо не существует, либо всегда замкнут
    int reading = digitalRead(pin);

    if (reading == HIGH) {
      initialized[i] = true;
      lastState[i] = HIGH;
      Serial.print("D");
      Serial.print(pin);
      Serial.print(" ");
      totalWorking++;
      workingPins[totalWorking - 1] = pin;
    }
    // Если LOW при старте — пропускаем (скорее всего не существует или GND)
  }

  Serial.println();
  Serial.println();
  Serial.print("Найдено рабочих пинов: ");
  Serial.println(totalWorking);
  Serial.print("Список: ");
  for (int i = 0; i < totalWorking; i++) {
    Serial.print("D"); Serial.print(workingPins[i]);
    if (i < totalWorking - 1) Serial.print(", ");
  }
  Serial.println();
  Serial.println();
  Serial.println("Нужно найти 9 штук (8 свитчей + кнопка питания).");
  Serial.println("Замыкай пины на GND и смотри сюда ↓");
  Serial.println("────────────────────────────────────────");
}

void loop() {
  unsigned long now = millis();

  for (int i = 0; i < PIN_COUNT; i++) {
    if (!initialized[i]) continue;

    int pin = TEST_PINS[i];
    bool cur = digitalRead(pin) == LOW; // LOW = замкнут на GND

    if (cur && !lastState[i]) {
      // Нажатие (HIGH → LOW, т.е. lastState был HIGH = не нажат)
      if (now - lastTrigger[i] > DEBOUNCE_MS) {
        lastTrigger[i] = now;

        Serial.print("▶ ЗАМКНУТ  D");
        Serial.print(pin);
        Serial.print("  (Arduino pin ");
        Serial.print(pin);
        Serial.print(", millis=");
        Serial.print(now);
        Serial.println(")");
      }
    }

    if (!cur && lastState[i]) {
      // Отпускание (LOW → HIGH)
      if (now - lastTrigger[i] > DEBOUNCE_MS) {
        Serial.print("  разомкнут D");
        Serial.println(pin);
      }
    }

    lastState[i] = cur;
  }
}

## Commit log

2026-05-29 Initial RutonyPad project
    [RutonyPad-Box-v3.2.stl, RutonyPad-Buttons-v1.1.stl]
2026-05-29 Фикс текст
2026-06-02 Add final case painting photos
2026-06-02 Add angled print photos
2026-06-02 Правки
2026-06-02 Правки README
2026-06-05 Add final assembly photos
2026-06-05 Clarify device modes
2026-06-05 Add soldering iron photo
2026-06-05 Update soldering and printer notes
